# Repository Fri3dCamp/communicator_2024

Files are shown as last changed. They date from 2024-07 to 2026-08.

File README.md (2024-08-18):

# Communicator 2024
In deze Git repository kan je de ontwerpbestanden en productiedata vinden van de [Fri3d Camp](https://fri3d.be/) 2024 communcator add-on. Revisie 01 is de versie die je in de zakjes kan terugvinden.

De PCB bevat volgende elementen:

- [LANA TNY](https://phyx.be/LANA_TNY/) controller bord voor het keyboard
- [I²S Microfoon](Datasheets/MIC.pdf)
- [I²S DAC met versterker](Datasheets/AMP.pdf)

In de zak zal je ook nog volgende items aantreffen:

- [Luidspreker](Datasheets/SPK.pdf)
- 2 lange pin headers
- Cover PCB
- 4 lange plastieken spacers
- 4 korte plastieken spacers

Je zal zelf de speaker en pin headers nog moeten solderen, het siliconen keyboard op de PCB monteren met de afdekplaat en het op de badge klikken.

Het keyboard werkt ook als USB keyboard. Maar plug de USB kabel niet in wanneer de badge verbonden is!

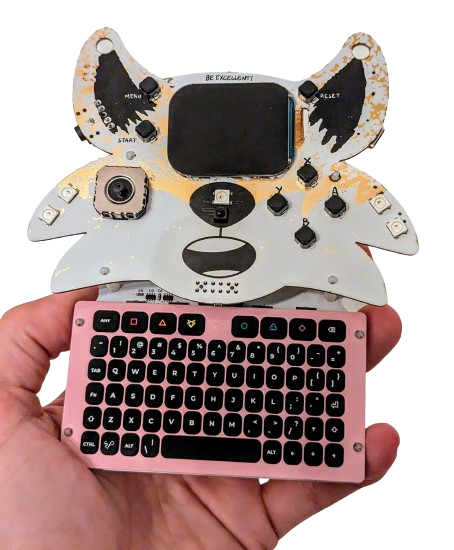
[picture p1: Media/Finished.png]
Communicator 2024 01


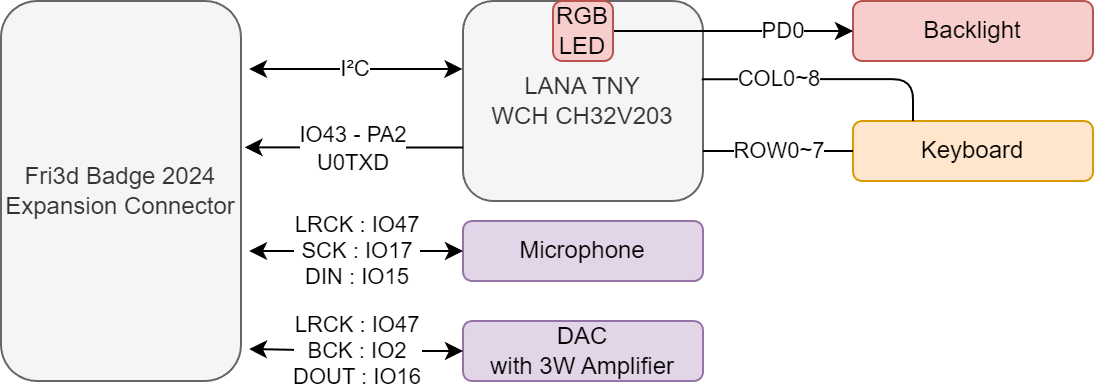
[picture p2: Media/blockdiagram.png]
Communicator 2024 01 blockdiagram


## Communicator 2024 (EN)
This repository contains the hardware design and production files for the [Fri3d Camp](https://fri3d.be/en/) 2024 Communicator add-on.

&nbsp;<br>
# Programming the LANA Module
To program the small [LANA](https://phyx.be/LANA_TNY/) module on your `communicator`, you can use either [Embeetle IDE](https://embeetle.com/) or [Mounriver Studio](http://www.mounriver.com/). Embeetle is an IDE of Belgian make. The LANA can be programmed directly via the USB-C connector but also with the [WCH-Link debugger](https://www.wch-ic.com/products/WCH-Link.html), which gives extra debugging options. <a href="https://embeetle.com/#supported-hardware/wch/boards/lana-tny-01">Click here</a> For the complete documentation on how to program the LANA module in Embeetle. The steps below show how to get started quickly to program your LANA module via its USB-C port.

&nbsp;<br>
## STEP 1: Download Embeetle IDE
First download Embeetle:
 - [https://embeetle.com/downloads](https://embeetle.com/#embeetle-ide/download)

You can download it for either **Windows** or **Linux**. We don't have MAC support yet.



&nbsp;<br>
## STEP 2: Launch the `lana-tny-01-communicator-2024` project
Launch Embeetle and click 'CREATE PROJECT':



&nbsp;<br>
Then select `WCH` for the vendor (that's the vendor of the microcontroller) and look for the project `lana-tny-01-communicator-2024`:



&nbsp;<br>
Now click `CREATE` at the bottom. Embeetle IDE will download the sample project and also all the required tools automatically. Then the project opens:



&nbsp;<br>
## STEP 3: Plug in the board
FIRST press the `BOOT` switch, THEN plug your board into the computer with a USB-C cable (while keeping the `BOOT` switch pressed):



When the board is plugged in, you can release the `BOOT` switch. This procedure ensures that your board is now in "bootloader mode". That means the microcontroller is ready to receive a new firmware!

&nbsp;<br>
## STEP 4: Flash the firmware
Now click the `flash` button at the top in Embeetle IDE. Embeetle will try to flash the firmware to the LANA module. However, you might experience the following error now:
```
Failed to open USB device: Bus 001 Device 008: ID 4348:55e0
Error: Failed to open USB device on Windows
```
On Linux you might experience another issue:
```
Failed to open USB device: Bus 003 Device 010: ID 4348:55e0
Error: Failed to open USB device on Linux due to no enough permission
```
Let's fix this.

&nbsp;<br>
## STEP 5a: Install Zadig (Windows only)
You must install [Zadig](https://zadig.akeo.ie/) and replace the driver for the USB device with the WinUSB driver. First, [download Zadig](https://zadig.akeo.ie/): 



&nbsp;<br>
Then, open Zadig and select **Options** -> **List All Devices**:



&nbsp;<br>
Select **USB Module** from the list of devices and choose **WinUSB** as the driver. Then click **Replace Driver**:



&nbsp;<br>
Maybe you didn't find **USB Module** in the list of devices? In that case, you might find **Unknown Device #1** instead. Take that one and choose **WinUSB** as the driver. Then click **Replace Driver**:



&nbsp;<br>
Wait for the driver installation to complete:



&nbsp;<br>
Success:



&nbsp;<br>
Try again in Embeetle IDE. It should work now:

```
"C:/Users/krist/EMBEETLE IDE/embeetle/beetle_tools/windows/wchisp_0.2.2_64b/wchisp.exe" flash application.elf
14:57:06 [INFO] Chip: CH32V203G6U6[0x3619] (Code Flash: 32KiB)
14:57:06 [INFO] Chip UID: CD-AB-19-97-D0-BC-B6-FF
14:57:06 [INFO] BTVER(bootloader ver): 02.70
14:57:06 [INFO] Code Flash protected: false
14:57:06 [INFO] Current config registers: a55aff0000ff00ffffffffff00020700cdab1997d0bcb6ff
RDPR_USER: 0x00FF5AA5
  [7:0]   RDPR 0xA5 (0b10100101)
    `- Unprotected
  [16:16] IWDG_SW 0x1 (0b1)
    `- IWDG enabled by the software, and disabled by hardware
  [17:17] STOP_RST 0x1 (0b1)
    `- Disable
  [18:18] STANDBY_RST 0x1 (0b1)
    `- Disable, entering standby-mode without RST
  [23:22] SRAM_CODE_MODE 0x3 (0b11)
    `- CODE-228KB + RAM-32KB / CODE-160KB + RAM-32KB depending on the chip
DATA: 0xFF00FF00
  [7:0]   DATA0 0x0 (0b0)
  [23:16] DATA1 0x0 (0b0)
WRP: 0xFFFFFFFF
  `- Unprotected
14:57:06 [INFO] Read application.elf as ELF format
14:57:06 [INFO] Found loadable segment, physical address: 0x00000000, virtual address: 0x00000000, flags: 0x5
14:57:06 [INFO] Section names: [".init", ".vector", ".text"]
14:57:06 [INFO] Found loadable segment, physical address: 0x00000dbc, virtual address: 0x20000000, flags: 0x6
14:57:06 [INFO] Section names: [".data"]
14:57:06 [INFO] Firmware size: 4096
14:57:06 [INFO] Erasing...
14:57:06 [WARN] erase_code: set min number of erased sectors to 8
14:57:06 [INFO] Erased 8 code flash sectors
14:57:07 [INFO] Erase done
14:57:07 [INFO] Writing to code flash...
██████████████████████████████████████ 4096/409614:57:07 [INFO] Code flash 4096 bytes written
14:57:08 [INFO] Verifying...
██████████████████████████████████████ 4096/409614:57:08 [INFO] Verify OK
14:57:08 [INFO] Now reset device and skip any communication errors
14:57:08 [INFO] Device reset
```

If it didn't work, pull out the LANA module and plug it back into your computer while pressing the `BOOT` switch (release the button a few seconds after you plugged it into the computer), to ensure it really is in "bootloader mode". If it still doesn't work, don't hesitate to contact us:
 - Email: kristof@embeetle.com
 - Whatsapp: +32(0) 496 90 75 44
 - Discord: @kristof-at-embeetle

&nbsp;<br>
## STEP 5b: Add device to plugdev group (Linux only)
On Linux you'll have to add the device to the **plugdev** group. First check groups related to the current user:
```
$ groups `whoami`
kristof : kristof adm cdrom sudo dip plugdev lpadmin lxd sambashare
```
If `plugdev` would not be listed, add the current user to that group: 
```
$ sudo useradd -G plugdev `whoami`
```
Figure out your device's Vendor ID and Product ID through the `$ lsusb` command: 
```
$ lsusb
Bus 001 Device 001: ID 1d6b:0002 Linux Foundation 2.0 root hub
Bus 002 Device 001: ID 1d6b:0003 Linux Foundation 3.0 root hub
Bus 003 Device 001: ID 1d6b:0002 Linux Foundation 2.0 root hub
Bus 003 Device 002: ID 046d:c548 Logitech, Inc. Logi Bolt Receiver
Bus 003 Device 003: ID 1a40:0101 Terminus Technology Inc. Hub
Bus 003 Device 004: ID 04f2:b75c Chicony Electronics Co., Ltd FHD Webcam
Bus 003 Device 005: ID 1a2c:4324 China Resource Semico Co., Ltd USB Keyboard
Bus 003 Device 006: ID 048d:6005 Integrated Technology Express, Inc. ITE Device(8291)
Bus 003 Device 007: ID 1bcf:2701 Sunplus Innovation Technology Inc. HD 720P webcam
Bus 003 Device 008: ID 048d:ce00 Integrated Technology Express, Inc. ITE Device(8291)
Bus 003 Device 009: ID 8087:0026 Intel Corp. AX201 Bluetooth
Bus 003 Device 011: ID 4348:55e0 WinChipHead
Bus 004 Device 001: ID 1d6b:0003 Linux Foundation 3.0 root hub
Bus 004 Device 002: ID 0bda:0316 Realtek Semiconductor Corp. Card Reader
```
Look for the line with `WinChipHead` (third to last). As you can see, the ID for my device consists of two 4-digit hex numbers: `ID 4348:55e0`. The first one is the Vendor ID, the second one the Product ID. Do not confuse them! 

In the console, navigate to `/etc/udev/rules.d` and list the contents of the directory:
```
$ cd /etc/udev/rules.d
$ ls
70-snap.core.rules
70-snap.firefox.rules
70-snap.snap-store.rules
```
Now create a new file, for example with the gedit editor: 
```
$ sudo gedit 10-probe.rules
```
You can name this file whatever you want, so long as it ends in `.rules`. Rules files by convention begin with a number. Linux parses rules files in lexical order, and the number makes it easy to see which files will be parsed first. Choosing a low number (like 10, as above) means that your file will be parsed before system rules files.

Now you need to add a line in the file that represents your device. If the file already existed (from a previous device you added this way), you can leave all the content as-is and just add a line at the bottom. The line you need to add is:
```
ATTRS{idVendor}=="4348", ATTRS{idProduct}=="55e0", MODE="666", GROUP="plugdev"
```
<small>Note: In older Ubuntu/Linux installations, you might need to replace 'ATTRS' with 'SYSFS' in the line below.</small>

Of course, fill in your own Vendor ID and Product ID! (although the ones above should be correct for the `LANA-TNY-01` board).
Save the file and close it. Now you need to tell Linux to reload the udev rules:
```
$ sudo udevadm trigger
```
Any member of the **plugdev** group should now be able to run `wchisp` without using sudo. 

Try again to flash in Embeetle IDE.
If it doesn't work, pull out the LANA module and plug it back into your computer while pressing the `BOOT` switch (release the button a few seconds after you plugged it into the computer), to ensure it really is in "bootloader mode". If it still doesn't work, don't hesitate to contact us:
 - Email: kristof@embeetle.com
 - Whatsapp: +32(0) 496 90 75 44
 - Discord: @kristof-at-embeetle

&nbsp;<br>
# Mounriver Studio
[Mounriver](http://www.mounriver.com/) is an IDE based on eclipse released by the chipmaker WCH. This works on Windows and there is a version for linux and possibly also for Mac, but the last 2 are a bit behind. [Mounriver](http://www.mounriver.com/) also gives false reports of viruses on many systems and violates the GPL license conditions of the GCC Compiler.

&nbsp;<br>
# Notes on LANA module
If you are going to work with the LANA TNY yourself, you have to pay attention to 1 thing (regardless of the IDE) that is that LANA does not have an external clock and must use the internal clock (HSI), this is also stated in the default sketch of [Embeetle](https://embeetle.com/).
If you accidentally "brick" your [LANA](https://phyx.be/LANA_TNY/) board, you can usually unbrick it via USB or by using the power reset feature of the [WCHISPTool](https://www.wch-ic.com/downloads/WCHISPTool_Setup_exe.html).

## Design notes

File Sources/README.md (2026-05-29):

## Fri3d Camp 2024 Communicator add-on firmware

This firmware runs on the Fri3d camp 2024 communicator add-on board, which is powered by the [LANA-TNY](https://phyx.be/LANA_TNY) module. This module only controls the keyboard part of the communicator. The audio related functions of the communicator are handled by the main MCU of Fri3d badge through the expansion connector. More information about the 2024 communicator addon can be found [here](https://fri3dcamp.github.io/badge_2024/en/communicator/) ([dutch](https://fri3dcamp.github.io/badge_2024/communicator)).

The firmware outputs [HID report packets](https://files.microscan.com/helpfiles/ms4_help_file/ms-4_help-02-46.html) on USB and UART on the expansion connector. So the 2024 communicator addon can be used standalone using the USB connector attached to a PC for use as a normal keyboard, or in combination with the Fri3d badge [2024](https://github.com/Fri3dCamp/badge_2024) or [2026](https://github.com/Fri3dCamp/badge_2026) using the expansion connector.

## HID Report packets

We use HID Subclass 1 A HID report packet consists of 8 bytes. The first byte indicates the modifier keys that have been pressed:

| Bit | Modifier Key |
|-|-|
| 7 | RIGHT GUI |
| 6 | RIGHT ALT |
| 5 | RIGHT SHIFT |
| 4 | RIGHT CTRL |
| 3 | LEFT GUI |
| 2 | LEFT ALT |
| 1 | LEFT SHIFT |
| 0 | LEFT CTRL |

The second byte is reserved, the remaining 6 bytes can contain a [HID keycode](https://gist.github.com/MightyPork/6da26e382a7ad91b5496ee55fdc73db2).

### I2C

The Fri3d badge [2024](https://github.com/Fri3dCamp/badge_2024) and [2026](https://github.com/Fri3dCamp/badge_2026) can communicate with the 2024 communicator add-on through I2C (address ```0x38```). The following registers can be used to interface/control with the add-on:

| Register (hex) | Name | Access | Bytes | description |
|-|-|-|-|-|
| 0x00 | Version number | R | 3 | Reports the firmware version number |
| 0x03 | current HID report packet | R | 8 | An 8-byte HID report packet (see above) |
| 0x0b | Configuration | R/W | 1 | a 1-byte configuration register (see below) |
| 0x0c | Backlight | R/W | 2 | Keyboard backlight intensity (0-100) |
| 0x0e | LANA RGB LED | R/W | 3 | LANA module RGB LED value (R,G,B) (2) |
| 0x11 | CAPS Lock indicator | R/W | 1 | CAPS lock LED indicator (2) |
2. not available on the [Fri3D communicator 2026](https://github.com/Fri3dCamp/communicator_2026)

The configuration is a 1-byte value with the following encoding:
| Bit | Name |
|-|-|
| \[7:2\] | reserved |
| 1 | reboot to bootloader |
| 0 | enable interrupt mode (not implemented yet) |

## Building

Use [platformio](https://platformio.org) to build this project. You should install the [ch32v platform package](https://github.com/Community-PIO-CH32V/platform-ch32v) as well. If you use the command line, build using:

```
pio run
```

## Flashing

To flash your 2024 communicator, unplug the USB cable, press and hold the boot button of the [LANA-TNY](https://phyx.be/LANA_TNY) module while plugging in the USB cable again. Then upload using the command:
```
pio run -t upload
```
It will use [wchisp](https://github.com/Community-PIO-CH32V/tool-wchisp) to flash the binary to the CH32V203 chip.

More info about flashing the LAN-TNY module can be found [here](https://fri3dcamp.github.io/badge_2024/en/communicator/programming/) ([dutch](https://fri3dcamp.github.io/badge_2024/communicator/programming/)).

## Usage

The keyboard presents itself as a HID input device.
The ```Fn``` key can be used to trigger special functions:
 * ```Fn+F1```: Put LANA LED to red (1)
 * ```Fn+F2```: Put LANA LED to orange (1)
 * ```Fn+F3```: Put LANA LED to yellow (1)
 * ```Fn+F4```: Put LANA LED to green (1)
 * ```Fn+F5```: Put LANA LED to blue (1)
 * ```Fn+F6```: Put LANA LED to purple (1)
 * ```Fn+Windows```: Put LANA LED off (1)
 * ```Fn+Backspace```: Delete
 * ```Fn+Up```: Page Up
 * ```Fn+Down```: Page Down
 * ```Fn+Left```: Home
 * ```Fn+Right```: End
 * ```Fn+Spacebar```: Toggle keyboard backlight
 * ```Fn+Right Shift```: Toggle Caps Lock
1. only on the 2024 communicator

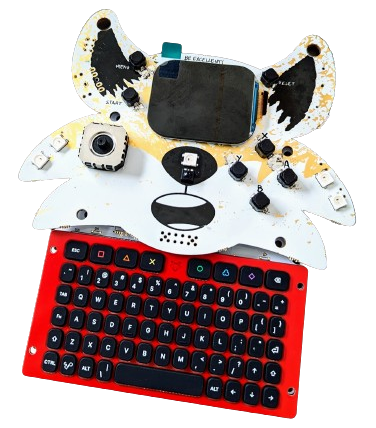
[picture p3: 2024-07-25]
Media/Prototype.png

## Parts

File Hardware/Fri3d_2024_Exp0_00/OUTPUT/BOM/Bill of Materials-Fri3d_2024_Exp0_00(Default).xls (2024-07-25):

Bill of Materials |  |  | Fri3D 2024 Exp0
Project: |  | Fri3d_2024_Exp0_00.PrjPcb
Revision: |  | 00
Variant: |  | Default
Creation Date: | 18/02/2024 | 20:35
Print Date: | 2024-04-03 | 14:17:22
Footprint | Comment | LibRef | Designator | Value | Description | Supplier 1 | Supplier Part Number 1 | Supplier 2 | Supplier Part Number 2 | Supplier 3 | Supplier Part Number 3 | Quantity
C0805_N |  | CAP # 10uF 10V 0805 | C1 | 10uF 10V | CAP # 10uF 10V 0805 | Farnell | 2320859 | LCSC | C17024 | Generic | 10uF 10V 0805 X7R | 1
C0603_N |  | CAP # 100nF 16V 0603 | C2, C8 | 100nF 16V | CAP # 100nF 16V 0603 | LCSC | C282519 |  |  | Generic | 100nF 16V 0603 X7R | 2
C0603_N |  | CAP # 220pF 50V 0603 | C3, C4 | 220pF | CAP # 220pF 50V 0603 | LCSC | C5254623 | LCSC | C107081 | Generic | 220pF 0603 | 2
C0603_N |  | CAP # 1uF 16V 0603 | C5, C6, C7 | 1uF 16V | CAP # 1uF 16V 0603 | Farnell | 2320814 | LCSC | C1592 | Generic | 1uF 16V 0603 X7R | 3
LITE_LTW-010DCG | Side emitting Cool White LED 3.0V 30mA 120° 2900mcd | LED # White Side Emitting LTW-010DCG-SR-G | D1, D2, D3, D4, D5, D6, D7, D9 | LTW-010DCG-SR-G | LED # White Side Emitting LTW-010DCG-SR-G | LCSC | C5175311 | LCSC | C5175309 | LCSC | C5175310 | 8
LED_0805_RD | Default 0805 Red LED | LED # Red 0805 | D8 |  | LED # Red 0805 | Farnell | 2099236 | LCSC | C965812 |  |  | 1
LED_5050_WS2812B_BLACK | WS2812 based digital RGB LED 5050 Black package | LED # RGB WS2812B-5050 BL | D10 | WS218B 5050 BL | LED # RGB WS2812B-5050 BL | Aliexpress | WS2812B Black 5050 | LCSC | C114586 |  |  | 1
L0603 | BLM18KG601SN1D | FER # 600R 1A3 0603 0R15 BLM18KG601SN1D | F1, F2 | 1A3 0R15 | FER # 600R 1A3 0603 0R15 BLM18KG601SN1D | Farnell | 1781094 |  |  |  |  | 2
PHYX_LANA_TNY_SMD | CH23V203 based TNY module | MOD # CH23V203 LANA TNY SMD | MOD1 | LANA TNY | MOD # CH23V203 LANA TNY SMD | Phyx | LANA TNY |  |  |  |  | 1
HDR2X6 | Header 6X2 | Pin Header 2.54mm dual row 12way | P1 |  | Pin Header 2.54mm dual row 12way |  |  |  |  |  |  | 1
R0603_N |  | RES # 0R 0603 | R1, R5 | 0R | RES # 0R 0603 | Farnell | 2447743 | LCSC | C95177 | Generic | 0R 1% 0603 | 2
R0603_N |  | RES # 100K 0603 | R2, R3, R6 | 100K | RES # 100K 0603 |  |  |  |  | Generic | 100K 1% 0603 | 3
R0603_N |  | RES # 1M 0603 | R4 | 1M | RES # 1M 0603 |  |  |  |  | Generic | 1M 1% 0603 | 1
Solder_Party_Keyb | Full QWERTY Keyboard Solder Party Dome Sheet | Solder_Party_Keyb | SW1 |  |  |  |  |  |  |  |  | 1
QFN_16_0.5_3X3 | Mono I²S DAC AMP 3W 2.5~5.5V | AMP # AUD MAX98357A | U1 | MAX98357A | AMP # AUD MAX98357A | Farnell | 2949165 |  |  |  |  | 1
WS_FSOP-8 | 3 Channel CC LED Driver 20mA | LED_DRVR # WS2811F FSOP-8 | U2, U3, U4 | WS2811F | LED_DRVR # WS2811F FSOP-8 | LCSC | C5446692 |  |  |  |  | 3
TDK_ICS-43434 | I2S MIC ICS-43434 | MIC # MEMS I2S ICS-43434 | U5 | ICS-43434 | MIC # MEMS I2S ICS-43434 | Mouser | 410-ICS-43434 | Farnell | 2911502 |  |  | 1
 |  |  |  |  |  |  |  |  |  |  |  | 34
Approved |  | Notes

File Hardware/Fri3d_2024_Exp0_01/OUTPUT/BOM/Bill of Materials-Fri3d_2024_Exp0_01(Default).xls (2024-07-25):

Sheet: BOM Report
Bill of Materials |  |  | Fri3D 2024 Exp0
Project: |  | Fri3d_2024_Exp0_01.PrjPcb
Revision: |  | 01
Variant: |  | Default
Creation Date: | 25/06/2024 | 16:23
Print Date: | 2024-07-23 | 8:57:20
Footprint | Comment | LibRef | Designator | Value | Description | Supplier 1 | Supplier Part Number 1 | Supplier 2 | Supplier Part Number 2 | Supplier 3 | Supplier Part Number 3 | Quantity | 200
C0805_N |  | CAP # 10uF 10V 0805 | C1 | 10uF 10V | CAP # 10uF 10V 0805 | Farnell | 2320859 | LCSC | C17024 | Generic | 10uF 10V 0805 X7R | 1 | 200
C0603_N |  | CAP # 100nF 16V 0603 | C2, C8 | 100nF 16V | CAP # 100nF 16V 0603 | LCSC | C282519 |  |  | Generic | 100nF 16V 0603 X7R | 2 | 400
C0603_N |  | CAP # 220pF 50V 0603 | C3, C4 | 220pF | CAP # 220pF 50V 0603 | LCSC | C5254623 | LCSC | C107081 | Generic | 220pF 0603 | 2 | 400
C0603_N |  | CAP # 1uF 16V 0603 | C5, C6, C7 | 1uF 16V | CAP # 1uF 16V 0603 | Farnell | 2320814 | LCSC | C1592 | Generic | 1uF 16V 0603 X7R | 3 | 600
LITE_LTW-010DCG | Side emitting Cool White LED 3.0V 30mA 120° 2900mcd | LED # White Side Emitting LTW-010DCG-SR-G | D1, D2, D3, D4, D5, D6, D7, D9 | LTW-010DCG-SR-G | LED # White Side Emitting LTW-010DCG-SR-G | LCSC | C5175311 | LCSC | C5175309 | LCSC | C5175310 | 8 | 1600
LED_0805_GR | Default 0805 Green LED | LED # Green 0805 | D8 |  | LED # Green 0805 | Farnell | 2099239 | LCSC | C965815 |  |  | 1 | 200
L0603 | BLM18KG601SN1D | FER # 600R 1A3 0603 0R15 BLM18KG601SN1D | F1, F2 | 1A3 0R15 | FER # 600R 1A3 0603 0R15 BLM18KG601SN1D | Farnell | 1781094 | LCSC | C85833 |  |  | 2 | 400
PHYX_LANA_TNY_SMD | CH23V203 based TNY module | MOD # CH23V203 LANA TNY SMD | MOD1 | LANA TNY | MOD # CH23V203 LANA TNY SMD | Phyx | LANA TNY |  |  |  |  | 1 | 200
HDR2X6 | Header 6X2 | Pin Header 2.54mm dual row 12way | P1 |  | Pin Header 2.54mm dual row 12way |  |  |  |  |  |  | 1 | 200
R0603_N |  | RES # 0R 0603 | R1, R5 | 0R | RES # 0R 0603 | Farnell | 2447743 | LCSC | C95177 / C15402 | Generic | 0R 1% 0603 | 2 | 400
R0603_N |  | RES # 100K 0603 | R3, R6 | 100K | RES # 100K 0603 | LCSC | C25803 | LCSC | C14675 | Generic | 100K 1% 0603 | 2 | 400
R0603_N |  | RES # 1M 0603 | R4 | 1M | RES # 1M 0603 | LCSC | C22935 | LCSC | C105578 | Generic | 1M 1% 0603 | 1 | 200
 | INGHAi GSPK3020035PN 8R 1W 100mm Leads | SPEAKER 8R 1W 10cm | SPK1 | GSPK3020035PN-8R1.0W-L100 | SPEAKER 8R 1W 10cm | LCSC | C530556 |  |  |  |  | 1 | 200
Solder_Party_Keyb | Full QWERTY Keyboard Solder Party Dome Sheet | Solder_Party_Keyb | SW1 |  |  |  |  |  |  |  |  | 1 | 200
QFN_16_0.5_3X3 | Mono I²S DAC AMP 3W 2.5~5.5V | AMP # AUD MAX98357A | U1 | MAX98357A | AMP # AUD MAX98357A | Farnell | 2949165 | LCSC | C910544 |  |  | 1 | 200
WS_FSOP-8 | 3 Channel CC LED Driver 20mA | LED_DRVR # WS2811F FSOP-8 | U2, U3, U4 | WS2811F | LED_DRVR # WS2811F FSOP-8 | LCSC | C5446692 |  |  |  |  | 3 | 600
TDK_ICS-43434 | I2S MIC ICS-43434 | MIC # MEMS I2S ICS-43434 | U5 | ICS-43434 | MIC # MEMS I2S ICS-43434 | Mouser | 410-ICS-43434 | Farnell | 2911502 |  |  | 1 | 200
 |  |  |  |  |  |  |  |  |  |  |  | 33 | 6600
Approved |  | Notes

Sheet: Sheet1
Footprint | LibRef | Designator | Value | Description | Quantity | 200
C0805_N | CAP # 10uF 10V 0805 | C1 | 10uF 10V | CAP # 10uF 10V 0805 | 1 | 200
C0603_N | CAP # 100nF 16V 0603 | C2, C8 | 100nF 16V | CAP # 100nF 16V 0603 | 2 | 400
C0603_N | CAP # 220pF 50V 0603 | C3, C4 | 220pF | CAP # 220pF 50V 0603 | 2 | 400
C0603_N | CAP # 1uF 16V 0603 | C5, C6, C7 | 1uF 16V | CAP # 1uF 16V 0603 | 3 | 600
LITE_LTW-010DCG | LED # White Side Emitting LTW-010DCG-SR-G | D1, D2, D3, D4, D5, D6, D7, D9 | LTW-010DCG-SR-G | LED # White Side Emitting LTW-010DCG-SR-G | 8 | 1600
LED_0805_GR | LED # Green 0805 | D8 |  | LED # Green 0805 | 1 | 200
L0603 | FER # 600R 1A3 0603 0R15 BLM18KG601SN1D | F1, F2 | 1A3 0R15 | FER # 600R 1A3 0603 0R15 BLM18KG601SN1D | 2 | 400
PHYX_LANA_TNY_SMD | MOD # CH23V203 LANA TNY SMD | MOD1 | LANA TNY | MOD # CH23V203 LANA TNY SMD | 1 | 200
HDR2X6 | Pin Header 2.54mm dual row 12way | P1 |  | Pin Header 2.54mm dual row 12way | 1 | 200
R0603_N | RES # 0R 0603 | R1, R5 | 0R | RES # 0R 0603 | 2 | 400
R0603_N | RES # 100K 0603 | R3, R6 | 100K | RES # 100K 0603 | 2 | 400
R0603_N | RES # 1M 0603 | R4 | 1M | RES # 1M 0603 | 1 | 200
 | SPEAKER 8R 1W 10cm | SPK1 |  | SPEAKER 8R 1W 10cm | 1 | 200
Solder_Party_Keyb | Solder_Party_Keyb | SW1 |  |  | 1 | 200
QFN_16_0.5_3X3 | AMP # AUD MAX98357A | U1 | MAX98357A | AMP # AUD MAX98357A | 1 | 200
WS_FSOP-8 | LED_DRVR # WS2811F FSOP-8 | U2, U3, U4 | WS2811F | LED_DRVR # WS2811F FSOP-8 | 3 | 600
TDK_ICS-43434 | MIC # MEMS I2S ICS-43434 | U5 | ICS-43434 | MIC # MEMS I2S ICS-43434 | 1 | 200

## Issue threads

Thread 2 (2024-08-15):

The `.beetle` folder is missing

kristofmulier, 2024-08-15:
I cloned the github repository and noticed that this is actually an Embeetle project: `communicator_2024-main/Sources/`

Only the `.beetle` folder is missing, which makes it hard to open it in Embeetle: you would have to manually select the tools, the device, etc etc before you can open it. To make it more convenient, it would be great to add this folder to the repo:

`communicator_2024-main/Sources/.beetle`

I've prepared one here:
https://new.embeetle.com/downloads/misc/lana-board/.beetle.7z

If you unzip and place this folder at `communicator_2024-main/Sources/.beetle`, the project will smoothly open in Embeetle IDE.

bertouttier, 2024-08-15:
Thanks for this suggestion! unfortunately, your link does not work for me.

kristofmulier, 2024-08-16:
Hi @bertouttier ,
It is no longer necessary. Meanwhile, I have added both the `blaster` and `communicator` projects to the Embeetle server, so anyone can access them there. You can find the documentation (step-by-step guide) here:

https://fri3dcamp.github.io/badge_2024/en/flamingo/programming/

and here:

https://fri3dcamp.github.io/badge_2024/en/communicator/programming/

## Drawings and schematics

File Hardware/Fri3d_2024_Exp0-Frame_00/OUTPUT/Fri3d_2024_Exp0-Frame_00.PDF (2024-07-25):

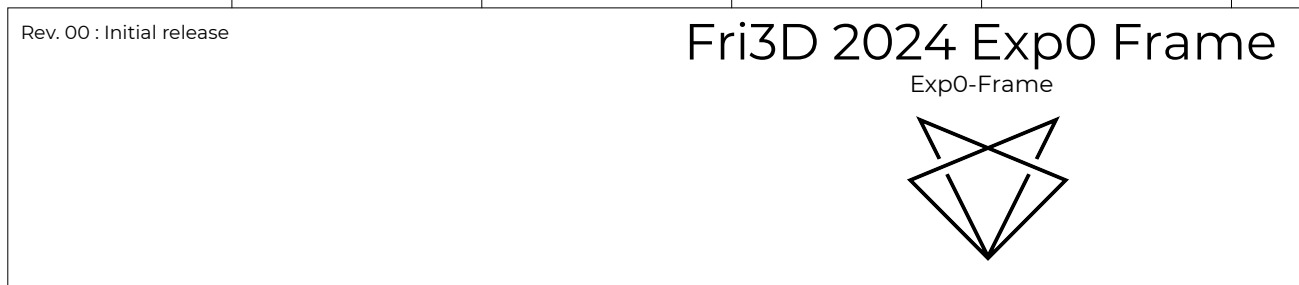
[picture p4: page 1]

Fri3D 2024 Exp0 Frame Rev. 00 : Initial release

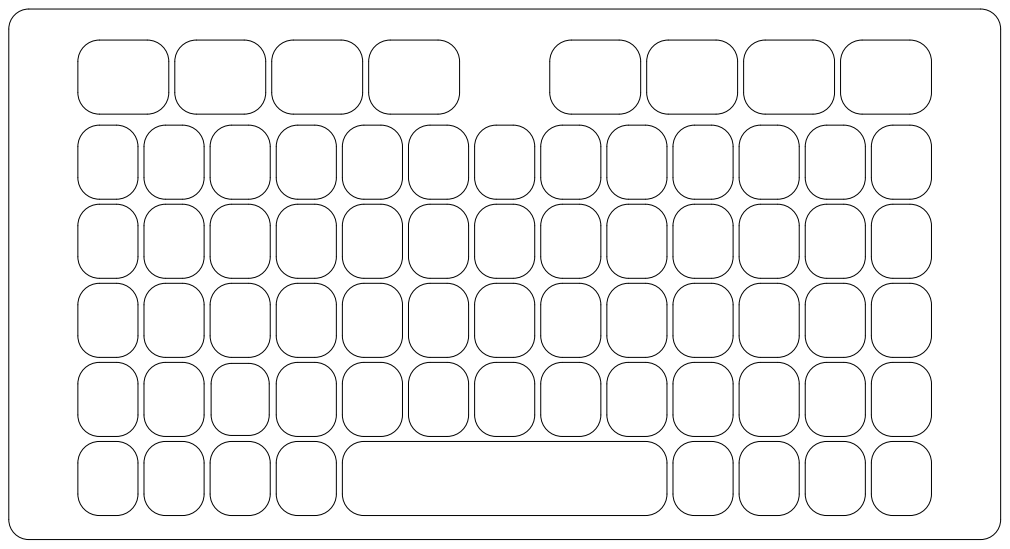
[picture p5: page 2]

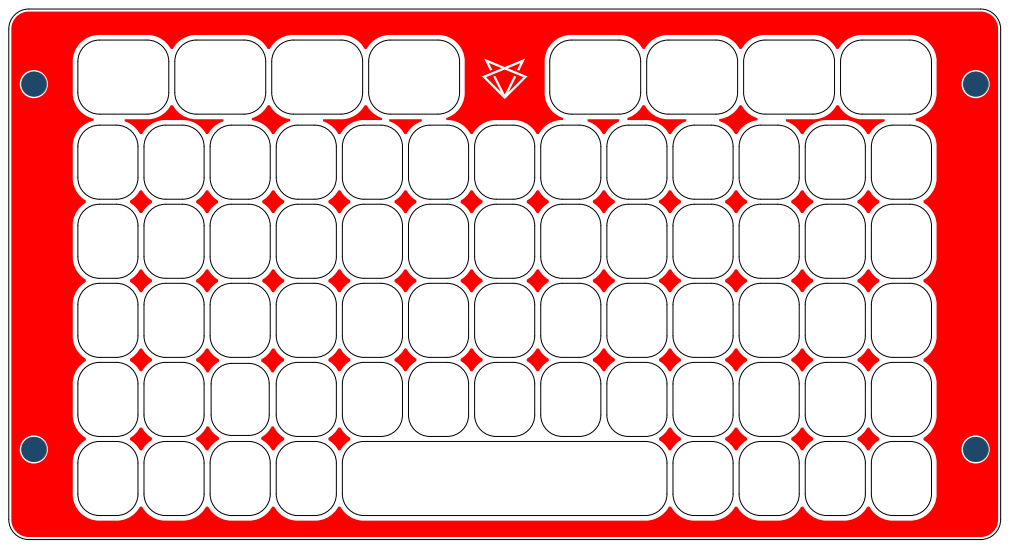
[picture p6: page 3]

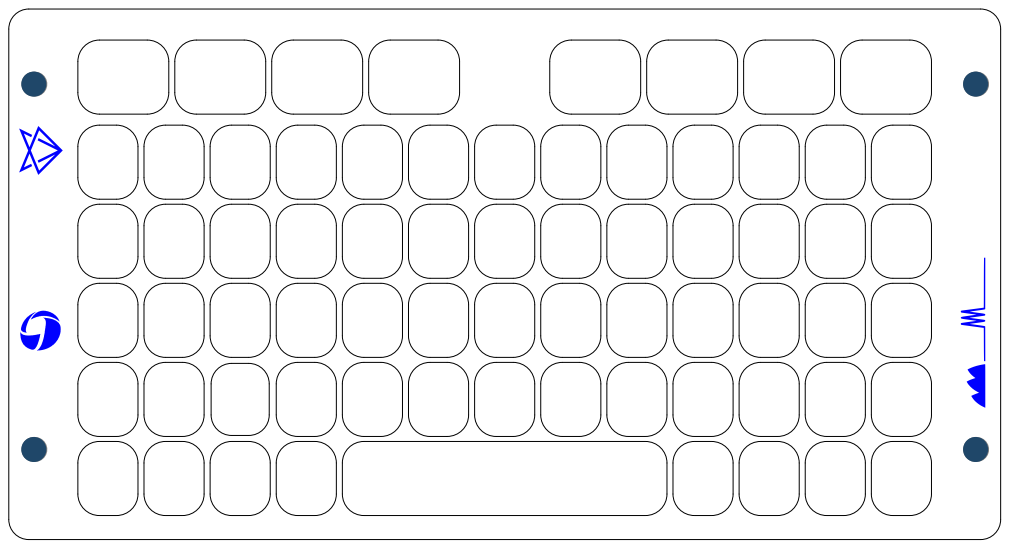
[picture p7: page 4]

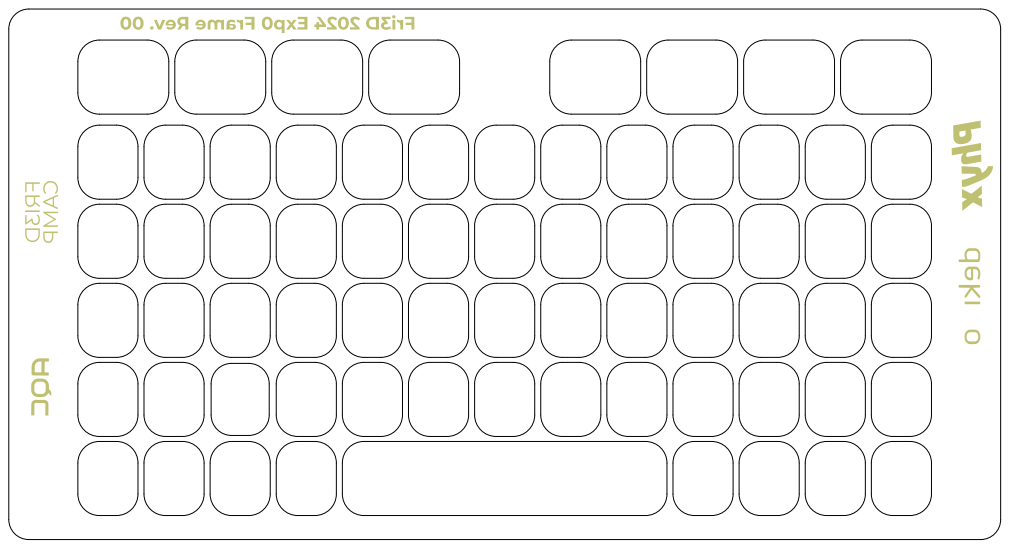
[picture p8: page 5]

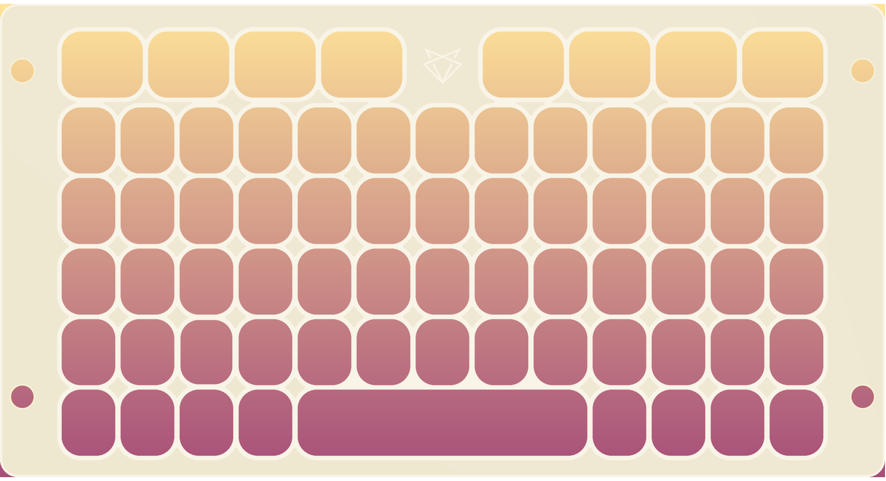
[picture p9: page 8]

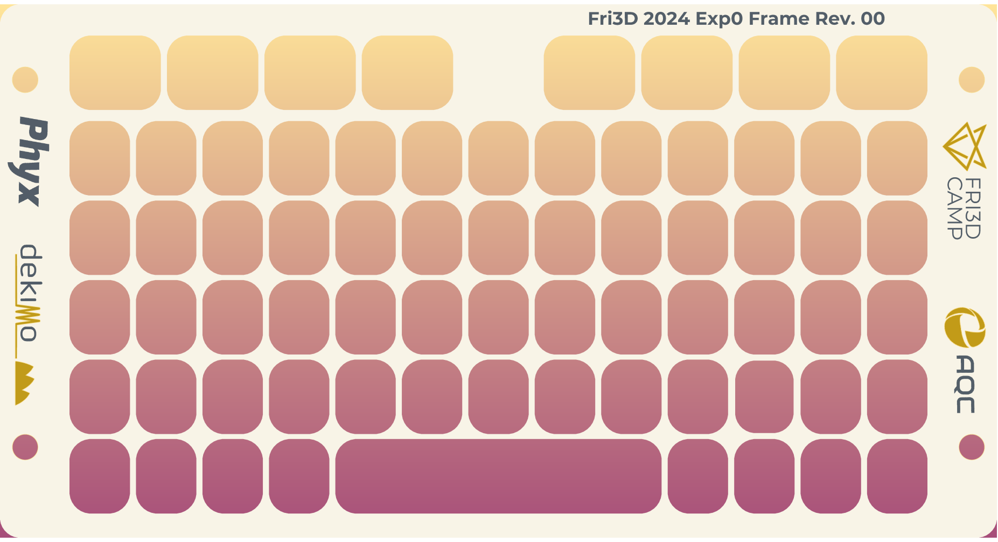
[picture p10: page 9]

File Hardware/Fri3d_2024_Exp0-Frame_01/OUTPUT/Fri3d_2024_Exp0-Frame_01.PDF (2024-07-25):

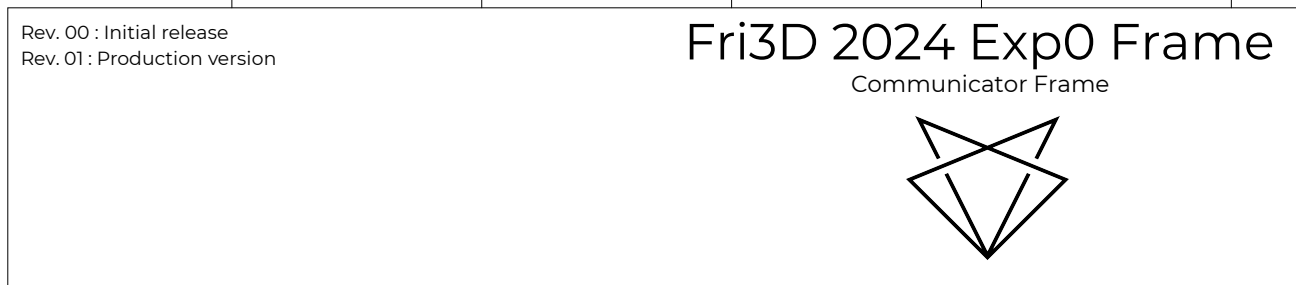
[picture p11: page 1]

Fri3D 2024 Exp0 Frame Rev. 00 : Initial release
Rev. 01 : Production version

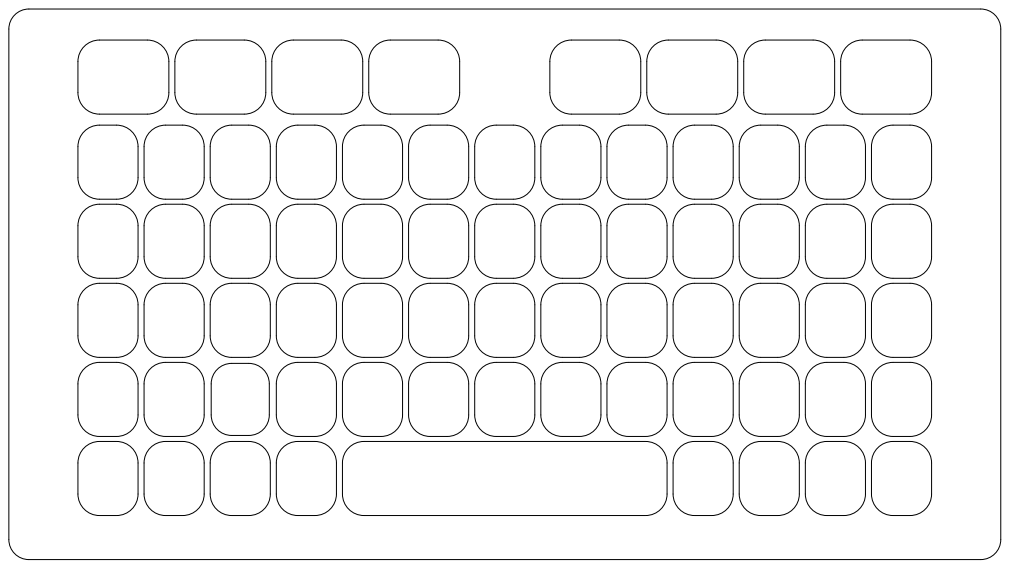
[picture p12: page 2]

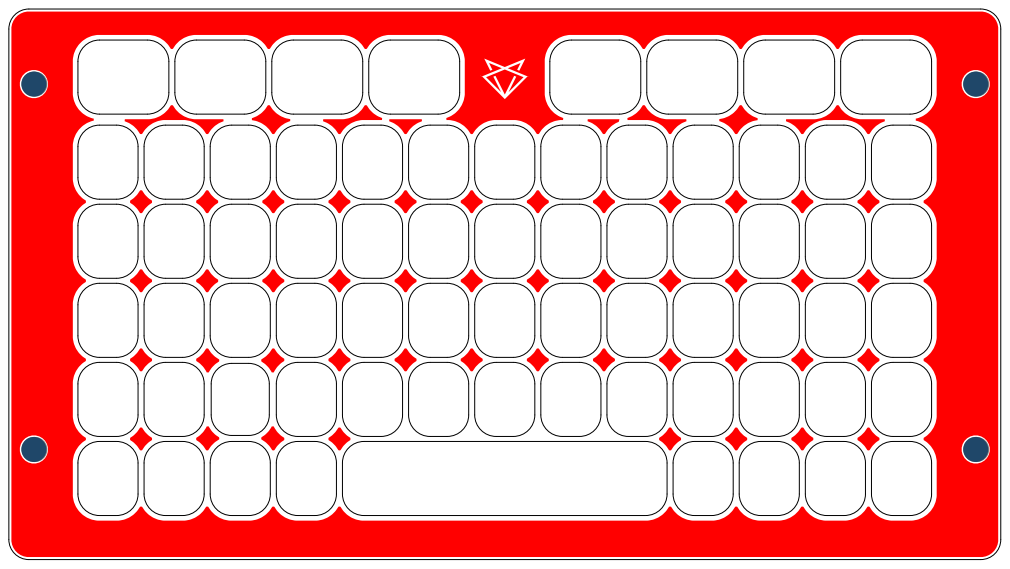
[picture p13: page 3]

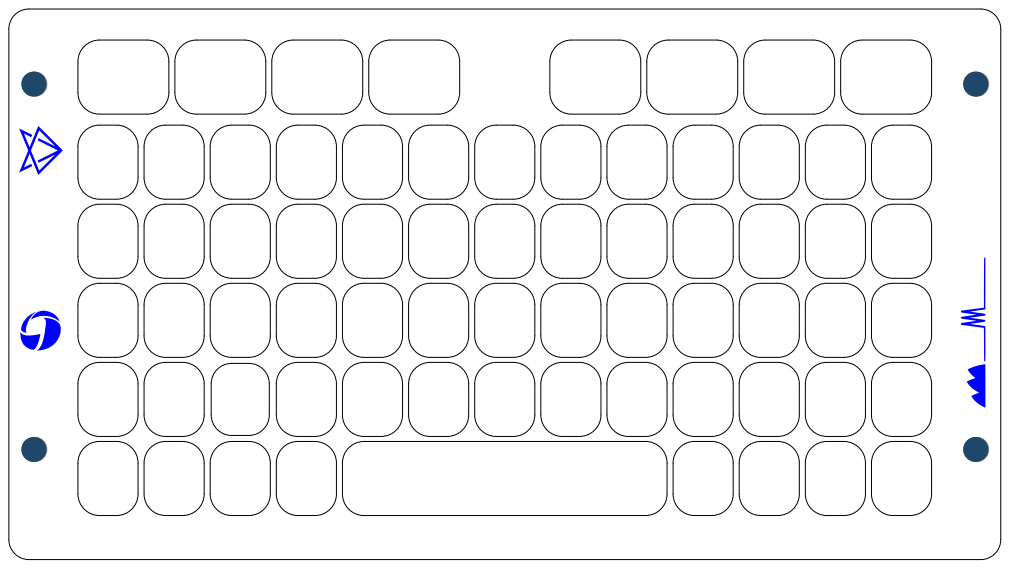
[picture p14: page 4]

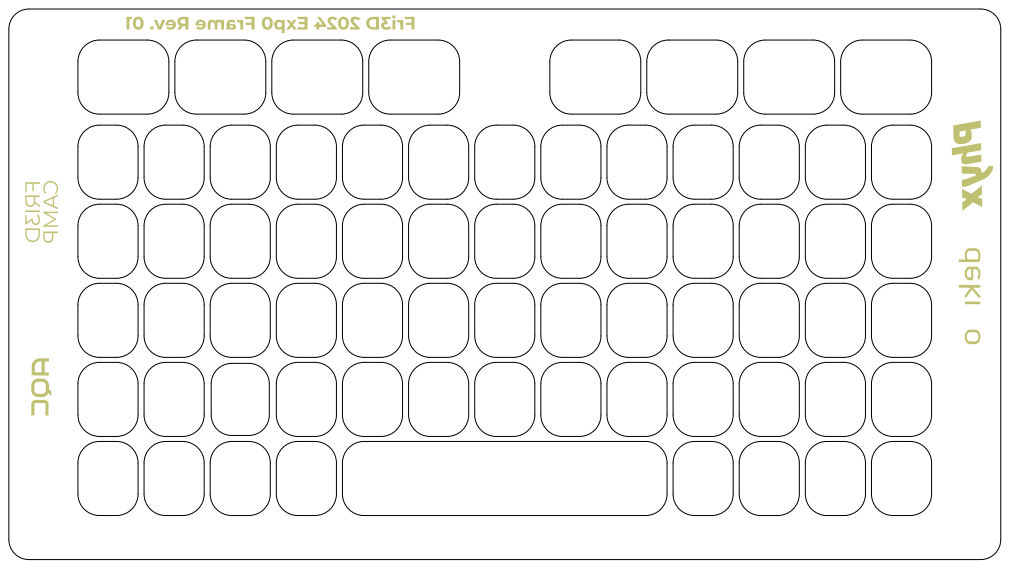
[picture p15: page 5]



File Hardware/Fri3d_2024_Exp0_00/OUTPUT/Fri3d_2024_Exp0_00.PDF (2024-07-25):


Full QWERTY Keyboard Solder Party Dome Sheet


Left / Right -> LR pin
Right -> Tie tot VDD
Left -> Tie to GND

Channel Selection: SD MODE pin
Left -> Tie tot VDD
Right -> PU 370kΩ
Left/2 + Right/2 -> PU 1MΩ
MAX98357A I²S Amplifier

Gain setting : GAIN pin
12dB -> Tie to GND
6dB -> Tie tot VDD









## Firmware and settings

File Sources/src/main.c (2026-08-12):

#include <ch32v20x.h>
#include <stdlib.h> /* atoi() */
#include <string.h> /* memset() */

#include <usb_lib.h>
#include <usb_pwr.h>

#include "keycodes.h"
/* we use our own custom debug lib
 * because the framework-wch-noneos-sdk does not allow UART4
 * as debug output
 */
#include "debug.h"

/* I2C on the expansion connector towards the badge */
#define SDA_PORT         GPIOB
#define SDA_PIN          GPIO_Pin_7
#define SCL_PORT         GPIOB
#define SCL_PIN          GPIO_Pin_6
#define I2C_ADDRESS      (0x38)
#define I2C_TIMEOUT      (-2)
#define I2C_TIMEOUT_TICK ((SystemCoreClock / 10) - 1) /* 100 ms */
#define I2C_SPEED        (400000)
#define UART_BAUDRATE    (115200)

/* digital outputs (button matrix) */
#define COL0_PORT GPIOB // PB4: col0
#define COL0_PIN  GPIO_Pin_4
#define COL1_PORT GPIOB // PB3: col1
#define COL1_PIN  GPIO_Pin_3
#define COL2_PORT GPIOA // PA0: col2
#define COL2_PIN  GPIO_Pin_0
#define COL3_PORT GPIOA // PA15: col3
#define COL3_PIN  GPIO_Pin_15
#define COL4_PORT GPIOA // PA1: col4
#define COL4_PIN  GPIO_Pin_1
#define COL5_PORT GPIOA // PA14: (SWC) col5
#define COL5_PIN  GPIO_Pin_14
#define COL6_PORT GPIOB // PB0: col6
#define COL6_PIN  GPIO_Pin_0
#define COL7_PORT GPIOA // PA13: (SWD) col7
#define COL7_PIN  GPIO_Pin_13
#define COL8_PORT GPIOB // PB1: col8
#define COL8_PIN  GPIO_Pin_1
#define N_COLS    (9)

#define ROW0_PORT GPIOD // PD1: row0
#define ROW0_PIN  GPIO_Pin_1
#define ROW1_PORT GPIOA // PA3: row1
#define ROW1_PIN  GPIO_Pin_3
#define ROW2_PORT GPIOA // PA5: row2
#define ROW2_PIN  GPIO_Pin_5
#define ROW3_PORT GPIOA // PA4: row3
#define ROW3_PIN  GPIO_Pin_4
#define ROW4_PORT GPIOA // PA6: row4
#define ROW4_PIN  GPIO_Pin_6
#define ROW5_PORT GPIOA // PA9: row5
#define ROW5_PIN  GPIO_Pin_9
#define ROW6_PORT GPIOA // PA7: row6
#define ROW6_PIN  GPIO_Pin_7
#define ROW7_PORT GPIOB // PB5: row7
#define ROW7_PIN  GPIO_Pin_5
#define N_ROWS    (8) // fits perfectly in uint8_t

#define TIMER_FREQ ((SystemCoreClock / 10000) - 1) /* the output frequency of all timers: 100Hz */

#define LED_PORT             GPIOD // PD0: Lana led
#define LED_PIN              GPIO_Pin_0
#define LED_LANA_OFFSET      (0)
#define LED_LANA_LEN         (3)
#define LED_BACKLIGHT_OFFSET (LED_LANA_OFFSET + LED_LANA_LEN)
#define LED_BACKLIGHT_LEN    (8)
#define LED_RED_OFFSET       (LED_BACKLIGHT_OFFSET + LED_BACKLIGHT_LEN)
#define LED_RED_LEN          (1)
#define N_LEDS               (LED_LANA_LEN + LED_BACKLIGHT_LEN + LED_RED_LEN) // 1 RGB led on LANA and 9 normal LEDs on the communicator

#define RESULT_BUFFER_SIZE      (3 + 8 + 1 + 2 + 3 + 1)
#define RESULT_KB_OFFSET        (3)
#define RESULT_CONFIG_OFFSET    (RESULT_KB_OFFSET + 8)
#define RESULT_BACKLIGHT_OFFSET (RESULT_CONFIG_OFFSET + 1)
#define RESULT_RGB_OFFSET       (RESULT_BACKLIGHT_OFFSET + 2)
#define RESULT_RED_OFFSET       (RESULT_RGB_OFFSET + 3)

#define HID_REPORT_KEYS (6)

typedef struct
{
    uint8_t r; // Red
    uint8_t g; // Green
    uint8_t b; // Blue
} ws2812b_color_t;

typedef struct
{
    uint8_t modifiers;
    uint8_t reserved;
    uint8_t keys[HID_REPORT_KEYS];
} key_report_t;

/*
 * This struct contains all data that is available through I2C.
 * Use the following command with a Buspirate to test:
 * read version number : [ 0x70 0x00 [ 0x71 r:3 ]
 * read key report : [ 0x70 0x03 [ 0x71 r:8 ]
 * read output : [ 0x70 0x0b [ 0x71 r:1 ]
 * read backlight : [ 0x70 0x0c [ 0x71 r:2 ]
 * turn off backlight : [ 0x70 0x0c 0x00 0x00 ]
 * turn on backlight : [ 0x70 0x0c 0x64 0x00 ]
 * read RGB led : [ 0x70 0x0e [ 0x71 r:3 ]
 * turn off RGB led : [ 0x70 0x0e 0x00:3 ]
 * turn on RGB led : [ 0x70 0x0e 0xFF:3 ]
 * turn on RGB led : [ 0x70 0x0e 0xFF 0x00 0x00 ]
 * turn on caps led : [ 0x70 0x11 0xFF ]
 * turn off caps led : [ 0x70 0x11 0x00 ]
 * read caps led: [ 0x70 0x11 [ 0x71 r ]
 */
typedef struct __attribute__((packed))
{
    uint8_t version[3];      // version number
    key_report_t key_report; // reference to the button state byte in the result buffer
    uint8_t enable_int : 1;  // configuration flag to enable interrupt output instead of UART output (TODO)
    uint8_t reboot : 1;      // configuration flag to trigger a reboot to bootloader
    uint8_t reserved : 6;    // reserved
    uint16_t backlight;      // backlight PWM value
    ws2812b_color_t rgb_led; // RGB led value
    uint8_t red_led;         // red LED value
} addon_data_t;

_Static_assert(sizeof(addon_data_t) == RESULT_BUFFER_SIZE, "raw data and struct size are not aligned!");

typedef struct
{
    uint8_t flag_matrix_scan_done : 1;    // flag to indicate that the button matrix state has changed
    uint8_t flag_int_should_clear : 1;    // flag to indicate that the interrupt should be cleared
    uint8_t flag_update_backlight : 1;    // flag to indicate that the backlight should be updated
    uint8_t flag_update_rgb : 1;          // flag to indicate that the LANA RGB LED should be updated
    uint8_t flag_update_red : 1;          // flag to indicate that the red LED should be updated
    uint8_t flag_update_leds : 1;         // flag to indicate that the LED state should be written to the WS2812 LEDs
    uint8_t flag_button_scan_halfway : 1; // flag to indicate that the matrix scan is halfway
    uint8_t flag_caps_lock : 1;           // flag to indicate that the caps lock has been activated
    uint8_t flag_slave_first_write;
    uint8_t matrix_state[N_COLS];         // current matrix state (9)
    uint8_t leds[N_LEDS];                 // current led state (12)
    uint8_t slave_offset;               /* register offset captured after the most recent ADDR+W. */
    uint8_t slave_position;             /* current read/write cursor, reset to offset on every ADDR (including repeated-START), so write-then-read works without special-casing. */
    uint8_t unused;
    union
    {
        addon_data_t data;
        uint8_t raw_data[RESULT_BUFFER_SIZE];
    };
} addon_state_t;

/* Global Variables */
static addon_state_t state;
volatile uint8_t KB_LED_Cur_Status = 0x00;
volatile uint8_t kb_led_last_status = 0x00; // last status of the keyboard LEDs
/* for USB lib */
uint8_t USBD_ENDPx_DataUp(uint8_t endp, uint8_t *pbuf, uint16_t len);

/* initialize timer 3 to periodically generate an interrupt */
static void TIM3_Init(uint16_t arr, uint16_t psc)
{
    TIM_TimeBaseInitTypeDef TIM_TimeBaseStructure = {0};
    NVIC_InitTypeDef NVIC_InitStructure = {0};

    /* Enable Timer3 Clock */
    RCC_APB1PeriphClockCmd(RCC_APB1Periph_TIM3, ENABLE);

    /* Initialize Timer3 */
    TIM_TimeBaseStructure.TIM_Period = arr;
    TIM_TimeBaseStructure.TIM_Prescaler = psc;
    TIM_TimeBaseStructure.TIM_ClockDivision = TIM_CKD_DIV1;
    TIM_TimeBaseStructure.TIM_CounterMode = TIM_CounterMode_Up;
    TIM_TimeBaseInit(TIM3, &TIM_TimeBaseStructure);

    /* enable timer interrupts */
    TIM_ITConfig(TIM3, TIM_IT_Update, ENABLE);

    /* configure timer interrupt */
    NVIC_InitStructure.NVIC_IRQChannel = TIM3_IRQn;
    NVIC_InitStructure.NVIC_IRQChannelPreemptionPriority = 1;
    NVIC_InitStructure.NVIC_IRQChannelSubPriority = 2;
    NVIC_InitStructure.NVIC_IRQChannelCmd = ENABLE;
    NVIC_Init(&NVIC_InitStructure);

    /* Enable Timer3 */
    TIM_Cmd(TIM3, ENABLE);
}

/* set a matrix column active */
static void KB_Set_Col(uint8_t col)
{
    switch (col)
    {
        case 0:
            GPIO_WriteBit(COL8_PORT, COL8_PIN, Bit_SET);
            GPIO_WriteBit(COL0_PORT, COL0_PIN, Bit_RESET);
            break;
        case 1:
            GPIO_WriteBit(COL0_PORT, COL0_PIN, Bit_SET);
            GPIO_WriteBit(COL1_PORT, COL1_PIN, Bit_RESET);
            break;
        case 2:
            GPIO_WriteBit(COL1_PORT, COL1_PIN, Bit_SET);
            GPIO_WriteBit(COL2_PORT, COL2_PIN, Bit_RESET);
            break;
        case 3:
            GPIO_WriteBit(COL2_PORT, COL2_PIN, Bit_SET);
            GPIO_WriteBit(COL3_PORT, COL3_PIN, Bit_RESET);
            break;
        case 4:
            GPIO_WriteBit(COL3_PORT, COL3_PIN, Bit_SET);
            GPIO_WriteBit(COL4_PORT, COL4_PIN, Bit_RESET);
            break;
        case 5:
            GPIO_WriteBit(COL4_PORT, COL4_PIN, Bit_SET);
            GPIO_WriteBit(COL5_PORT, COL5_PIN, Bit_RESET);
            break;
        case 6:
            GPIO_WriteBit(COL5_PORT, COL5_PIN, Bit_SET);
            GPIO_WriteBit(COL6_PORT, COL6_PIN, Bit_RESET);
            break;
        case 7:
            GPIO_WriteBit(COL6_PORT, COL6_PIN, Bit_SET);
            GPIO_WriteBit(COL7_PORT, COL7_PIN, Bit_RESET);
            break;
        case 8:
            GPIO_WriteBit(COL7_PORT, COL7_PIN, Bit_SET);
            GPIO_WriteBit(COL8_PORT, COL8_PIN, Bit_RESET);
            break;
        default:
            /* disable all */
            GPIO_WriteBit(GPIOA, COL2_PIN | COL3_PIN | COL4_PIN | COL5_PIN | COL7_PIN, Bit_SET);
            GPIO_WriteBit(GPIOB, COL0_PIN | COL1_PIN | COL6_PIN | COL8_PIN, Bit_SET);
    }
}

/* Initialize the I2C perfipheral and activate interrupts */
static void IIC_Init(uint32_t bound, uint16_t address)
{
    GPIO_InitTypeDef GPIO_InitStructure = {0};
    I2C_InitTypeDef I2C_InitStructure = {0};
    NVIC_InitTypeDef NVIC_InitStruct = {0};

    RCC_APB2PeriphClockCmd(RCC_APB2Periph_GPIOB | RCC_APB2Periph_AFIO, ENABLE);
    RCC_APB1PeriphClockCmd(RCC_APB1Periph_I2C1, ENABLE);

    /* configure the SDA and SCL pins */
    GPIO_InitStructure.GPIO_Pin = SDA_PIN | SCL_PIN;
    GPIO_InitStructure.GPIO_Mode = GPIO_Mode_AF_OD;
    GPIO_InitStructure.GPIO_Speed = GPIO_Speed_50MHz;
    GPIO_Init(GPIOB, &GPIO_InitStructure);

    /* configure I2C1 */
    I2C_InitStructure.I2C_ClockSpeed = bound;                                 // bus speed
    I2C_InitStructure.I2C_Mode = I2C_Mode_I2C;                                // there is only 1 mode
    I2C_InitStructure.I2C_DutyCycle = I2C_DutyCycle_16_9;                     // I2C fast mode Tlow/Thigh = 16/9
    I2C_InitStructure.I2C_OwnAddress1 = address << 1;                         // 7 or 10 bit address
    I2C_InitStructure.I2C_Ack = I2C_Ack_Enable;                               // automatic acknowledge
    I2C_InitStructure.I2C_AcknowledgedAddress = I2C_AcknowledgedAddress_7bit; // use 7 bit address
    I2C_Init(I2C1, &I2C_InitStructure);

    /* configure I2C interrupts */
    NVIC_InitStruct.NVIC_IRQChannel = I2C1_EV_IRQn;
    NVIC_InitStruct.NVIC_IRQChannelPreemptionPriority = 0;
    NVIC_InitStruct.NVIC_IRQChannelSubPriority = 1;
    NVIC_InitStruct.NVIC_IRQChannelCmd = ENABLE;
    NVIC_Init(&NVIC_InitStruct);

    NVIC_InitStruct.NVIC_IRQChannel = I2C1_ER_IRQn;
    NVIC_InitStruct.NVIC_IRQChannelPreemptionPriority = 0;
    NVIC_InitStruct.NVIC_IRQChannelSubPriority = 1;
    NVIC_InitStruct.NVIC_IRQChannelCmd = ENABLE;
    NVIC_Init(&NVIC_InitStruct);

    /* Enable I2C event, error, and buffer interrupts.
     * EVT fires on: address match, byte received, byte transmitted, stop detected.
     * ERR fires on: bus error, arbitration lost, acknowledge failure, etc.
     * BUF fires on: TXE/RXNE (needed so we get an interrupt for each data byte).
     */
    I2C_ITConfig(I2C1, I2C_IT_EVT | I2C_IT_ERR | I2C_IT_BUF, ENABLE);

    /* enable clock stretching */
    I2C_StretchClockCmd(I2C1, ENABLE);

    /* enable I2C1 */
    I2C_Cmd(I2C1, ENABLE);
}

/* initialize the WS2812 LED pin */
static void LED_Init_Neopixel(void)
{
    RCC_APB2PeriphClockCmd(RCC_APB2Periph_AFIO, ENABLE);
    RCC_APB2PeriphClockCmd(RCC_APB2Periph_GPIOD, ENABLE);

    /* remap OSC_IN/OSC_OUT as PD0/PD1, which is used as LEDDATA/row0 */
    GPIO_PinRemapConfig(AFIO_PCFR1_PD01_REMAP, ENABLE);

    GPIO_InitTypeDef GPIO_InitStructure = {0};
    GPIO_InitStructure.GPIO_Pin = LED_PIN;
    GPIO_InitStructure.GPIO_Mode = GPIO_Mode_Out_PP;
    GPIO_InitStructure.GPIO_Speed = GPIO_Speed_50MHz;
    GPIO_Init(LED_PORT, &GPIO_InitStructure);
}
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
int main(void)
{
    uint8_t status;
    uint8_t previous_matrix_state[N_COLS];
    key_report_t key_report;

    memset(previous_matrix_state, 0, N_COLS);
    memset(&key_report, 0, sizeof(key_report_t));

    /* set all data and flags to 0 */
    memset(&state, 0, sizeof(addon_state_t));

    /* set the version number from git */
    char version_major[] = VERSION_MAJOR;
    char version_minor[] = VERSION_MINOR;
    char version_patch[] = VERSION_PATCH;
    state.data.version[0] = atoi(version_major) & 0xff;
    state.data.version[1] = atoi(version_minor) & 0xff;
    state.data.version[2] = atoi(version_patch) & 0xff;

    NVIC_PriorityGroupConfig(NVIC_PriorityGroup_1);
    SystemCoreClockUpdate();
    Delay_Init();

    /* always configure the UART2 as TX */
    USART_Output_Init(UART_BAUDRATE);

    /* initialize i2c */
    IIC_Init(I2C_SPEED, I2C_ADDRESS);

    /* makes sure that we can still flash using SWD */
    Delay_Ms(1000);

    PRINT("SystemClk: %u\r\n", (unsigned)SystemCoreClock);
    PRINT("ChipID: %08x\r\n", (unsigned)DBGMCU_GetCHIPID());

    LED_Init_Neopixel();

    /* Initialize GPIO for keyboard scan */
    KB_Scan_Init(); // disables SWD and remap PD01 as GPIO
    KB_Sleep_Wakeup_Cfg();

    /* Initialize timer for Keyboard and mouse scan timing */
    TIM3_Init(1, TIMER_FREQ); // every 10 ms

    /* Initialize USBFS interface to communicate with the host  */
    Set_USBConfig();
    USB_Init();
    USB_Interrupts_Config();

    /* 2 breath pulses of the backlight */
    boot_animation();

    while (1)
    {
        if (KB_LED_Cur_Status != kb_led_last_status)
        {
            if ((KB_LED_Cur_Status & 0x01) != (kb_led_last_status & 0x01))
            {
                if (KB_LED_Cur_Status & 0x01)
                {
                    state.data.rgb_led.g = 255;
                    state.flag_update_rgb = 1;
                }
                else
                {
                    state.data.rgb_led.g = 0;
                    state.flag_update_rgb = 1;
                }
            }
            if ((KB_LED_Cur_Status & 0x02) != (kb_led_last_status & 0x02))
            {
                if (KB_LED_Cur_Status & 0x02)
                {
                    state.data.red_led = 0xff;
                    state.flag_update_red = 1;
                }
                else
                {
                    state.data.red_led = 0x00;
                    state.flag_update_red = 1;
                }
            }
            if ((KB_LED_Cur_Status & 0x04) != (kb_led_last_status & 0x04))
            {
                if (KB_LED_Cur_Status & 0x04)
                {
                    state.data.rgb_led.b = 255;
                    state.flag_update_rgb = 1;
                }
                else
                {
                    state.data.rgb_led.b = 255;
                    state.flag_update_rgb = 1;
                }
            }
            kb_led_last_status = KB_LED_Cur_Status;
        }

        if (state.flag_update_backlight)
        {
            state.flag_update_backlight = 0;
            LED_Backlight_SetBrightness(state.data.backlight);
            state.flag_update_leds = 1;
        }

        if (state.flag_update_rgb)
        {
            state.flag_update_rgb = 0;
            LED_Lana_SetColour(state.data.rgb_led);
            state.flag_update_leds = 1;
        }

        // a new red led value was written through I2C or USB
        if (state.flag_update_red)
        {
            state.flag_update_red = 0;
            state.leds[LED_RED_OFFSET] = state.data.red_led;
            state.flag_update_leds = 1;
        }

        if (state.flag_button_scan_halfway && state.data.enable_int)
        {
            state.flag_button_scan_halfway = 0;
            // TODO: set interrupt pin low
        }

        if (state.flag_matrix_scan_done)
        {
            state.flag_matrix_scan_done = 0;

            if (memcmp(state.matrix_state, previous_matrix_state, N_COLS) != 0)
            {
                // matrix state has changed
                for (int c = 0; c < N_COLS; c++)
                {
                    if (state.matrix_state[c] != previous_matrix_state[c])
                    {
                        for (int r = 0; r < N_ROWS; r++)
                        {
                            uint8_t current_button_state = (state.matrix_state[c] & (1 << r)) & 0xff;
                            uint8_t previous_button_state = (previous_matrix_state[c] & (1 << r)) & 0xff;

                            if (current_button_state != previous_button_state)
                            {
                                uint8_t keycode;
                                uint8_t is_modifier = get_keycode(c, r, &keycode);
                                if (is_modifier != 2)
                                {
                                    determine_hid_report(keycode, is_modifier, current_button_state, &key_report);
                                }
                            }
                        }
                    }
                }

                /* Copy the keyboard data to the buffer of endpoint 1 and set the data uploading flag */
                memcpy(previous_matrix_state, state.matrix_state, N_COLS);

                /* handle special FN triggers */
                handle_fn(&key_report, &state.data.key_report);

                /* the key report is ready to be fetched through I2C, so let's set the interrupt */
                if (state.data.enable_int)
                {
                    // TODO: set the UART TX to high
                    PRINT("TODO: set the output pin\r\n");
                }
                else
                {
#if (DEBUG)
                    PRINT("Reporting HID through UART:\r\n");
                    for (int i = 0; i < sizeof(key_report_t); i++)
                    {
                        PRINT("0x%02x ", state.raw_data[RESULT_KB_OFFSET + i]);
                    }
                    PRINT("\r\n");
#else
                    for (int i = 0; i < sizeof(key_report_t); i++)
                    {
                        while (USART_GetFlagStatus(USART2, USART_FLAG_TC) == RESET)
                            ;
                        USART_SendData(USART2, state.raw_data[RESULT_KB_OFFSET + i]);
                    }
#endif
                }

                if (bDeviceState == CONFIGURED)
                {
                    status = USBD_ENDPx_DataUp(ENDP1, &state.raw_data[RESULT_KB_OFFSET], sizeof(key_report_t));
                    if (status != USB_SUCCESS)
                    {
                        PRINT("ERROR reporting HID through USB\r\n");
                    }
                }
            }
        }

        /* wwrite the new led state to the leds */
        if (state.flag_update_leds)
        {
            PRINT("Writing new state to leds\r\n");
            state.flag_update_leds = 0;
            WS2812BSimpleSend(LED_PORT, LED_PIN, state.leds, N_LEDS);
        }
    }
}

/*********************************************************************
 * @fn      USB_Sleep_Wakeup_CFG
 *
 * @brief   Configure USB wake up mode
 *
 * @return  none
 */
void USB_Sleep_Wakeup_CFG(void)
{
    EXTI_InitTypeDef EXTI_InitStructure = {0};

    EXTI_InitStructure.EXTI_Line = EXTI_Line20;
    EXTI_InitStructure.EXTI_Mode = EXTI_Mode_Event;
    EXTI_InitStructure.EXTI_Trigger = EXTI_Trigger_Rising;
    EXTI_InitStructure.EXTI_LineCmd = ENABLE;
    EXTI_Init(&EXTI_InitStructure);
}

/*********************************************************************
 * @fn      MCU_Sleep_Wakeup_Operate
 *
 * @brief   Perform sleep operation
 *
 * @return  none
 */
void MCU_Sleep_Wakeup_Operate(void)
{
    PRINT("Sleep\r\n");
    __disable_irq();
    // keyboard interrupt lines
    RCC_APB1PeriphClockCmd(RCC_APB1Periph_PWR, ENABLE);
    EXTI_ClearFlag(EXTI_Line1 | EXTI_Line3 | EXTI_Line4 | EXTI_Line5 | EXTI_Line6 | EXTI_Line7 | EXTI_Line9);

    PWR_EnterSTOPMode(PWR_Regulator_LowPower, PWR_STOPEntry_WFE);

    SystemInit();
    SystemCoreClockUpdate();
    Set_USBConfig();

    if (EXTI_GetFlagStatus(EXTI_Line1 | EXTI_Line3 | EXTI_Line4 | EXTI_Line5 | EXTI_Line6 | EXTI_Line7 | EXTI_Line9) != RESET)
    {
        EXTI_ClearFlag(EXTI_Line1 | EXTI_Line3 | EXTI_Line4 | EXTI_Line5 | EXTI_Line6 | EXTI_Line7 | EXTI_Line9);
        Resume(RESUME_INTERNAL);
    }
    else if (EXTI_GetFlagStatus(EXTI_Line18) != RESET)
    {
        EXTI_ClearFlag(EXTI_Line18);
        PRINT("USB Wake Up\n");
    }
    __enable_irq();
    PRINT("Wake\r\n");
}

/* interrupt handlers */
void I2C1_IRQHandler(void) __attribute__((interrupt("WCH-Interrupt-fast")));
void I2C1_IRQHandler(void)
{
    PRINT("I2C1_IRQHandler\r\n");
}
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

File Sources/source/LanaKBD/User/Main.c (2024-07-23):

/********************************** (C) COPYRIGHT *******************************
* File Name          : main.c
* Author             : Bert Outtier
* Version            : V1.0.0
* Date               : 2024/06/17
* Description        : Main program body.
*********************************************************************************
* Copyright (c) 2024 Fri3D Camp
*******************************************************************************/

/*
 * @Note
 * Lana Keyboard:
 * This codes runs on the Lana board mounted on the Fri3D Badge 2024 keyboard expansion.
 * It presents as a USB HID device over USB and it also uses USART2 (TX only)
 * to send the HID reports to the badge.
 *
 */

#include "debug.h"
#include "usb_lib.h"
#include "usb_desc.h"
#include "usb_pwr.h"
#include "usb_prop.h"
#include "usbd_composite_km.h"

#define I2C_ADDRESS   0x38
#define I2C_SPEED     400000

/*********************************************************************
 * @fn      main
 *
 * @brief   Main program.
 *
 * @return  none
 */
int main(void)
{
    NVIC_PriorityGroupConfig(NVIC_PriorityGroup_2);
    Delay_Init();
    USART_Badge_Init(115200);

    /* initialize i2c */
    IIC_Init(I2C_SPEED, I2C_ADDRESS);

    /* makes sure that we can still flash using SWD */
    Delay_Ms(500);

    LED_Init_Neopixel();

    /* Initialize GPIO for keyboard scan */
    KB_Scan_Init();
    KB_Sleep_Wakeup_Cfg();

    /* Initialize timer for Keyboard and mouse scan timing */
    TIM3_Init(1, SystemCoreClock / 10000 - 1);

    /* initialize the USB HID endpoints */
    Set_USBConfig();
    USB_Init();
    USB_Interrupts_Config();

    while(1)
    {
        /* Handle keyboard scan data */
        KB_Scan_Handle();
    }
}

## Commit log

2024-07-25 Hardware added
    [Bill of Materials-Fri3d_2024_Exp0_00(Default).xls, Bill of Materials-Fri3d_2024_Exp0_01(Default).xls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]
2024-07-31 switch to wchisp flash tool
2026-03-04 total rewrite including i2c slave
2026-08-12 fix I2C slave
